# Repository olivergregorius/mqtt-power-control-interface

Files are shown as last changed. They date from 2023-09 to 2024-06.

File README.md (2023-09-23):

# mqtt-power-control-interface



## Introduction

Micropython project for front panel header power control using the MQTT protocol

## Hardware

This project includes a Kicad project providing schematics and a board layout for placing a Raspberry Pi Pico W on it. The microcontroller acts as a lightweight
MQTT client publishing and controlling the power state of up to 12 devices that are connected via the "Intel 9-pin header" (front panel header):

!TODO include picture of front panel header here!

The microcontroller and the devices are not directly connected, instead, they are galvanically isolated from each other by optocouplers, mitigating the risk of
damage.

The power state is determined by the state of the device's power LED pins. It is active low from the microcontroller's perspective.

The power state is controlled by shorting the device's power button pins for 500 milliseconds. That means if the device initially is powered off, it will be
powered on after the power button pins have been shortened. Powering off the machine is up to the operating system's power management, e.g. on Ubuntu if the
power button is pressed shortly (500 milliseconds are sufficient) a shutdown will be initiated, powering off the device.

Thus, each device can be controlled by two GPIO pins of the microcontroller: one for the power state check, one for the power button control.

## Software

This project is written in Micropython and can be flashed onto various microcontroller boards, e.g. the Raspberry Pi Pico W.

### Required Libraries

- umqtt.simple
- micropython_ota (see [https://github.com/olivergregorius/micropython_ota](https://github.com/olivergregorius/micropython_ota))
- micropython_loki (see [https://github.com/olivergregorius/micropython_loki](https://github.com/olivergregorius/micropython_loki))

### Required Files

The following files are required to be flashed onto the microcontroller:

- `boot.py` - Bootup script containing routines for establishing WiFi connection and installing required libraries
- `mqtt.py` - MQTT client library
- `types.py` - Utility file containing type definitions
- `utils.py` - Utility file containing utility methods
- `main.py` - Main routine
- `config.py` - Config file, see `config.template.py` as reference, the keys are self explanatory

### Message Formats

The message format is JSON.

#### Power State

The power state for each device is published to the topic defined in the config in a dedicated message for each device:

```json
{
    "deviceName": "device1",
    "state": "stopped"
}
```

The `state` attribute can take the values `stopped` and `running`.

#### Power Control

The power state for each device can be controlled by sending a dedicated message for each device to the defined topic in the config:

```json
{
    "deviceName": "device1",
    "action": "powerOn"
}
```

The `action` attribute can take the values `powerOn` and `powerOff`, whereas for now both of the actions trigger a 500 millisecond power button push, regardless
of the current state of the device.

## Disclaimer

This hardware/software is provided "as is", and you use the hardware/software at your own risk. Under no circumstances shall any author be liable for direct,
indirect, special, incidental, or consequential damages resulting from the use, misuse, or inability to use this hardware/software, even if the authors have
been advised of the possibility of such damages.

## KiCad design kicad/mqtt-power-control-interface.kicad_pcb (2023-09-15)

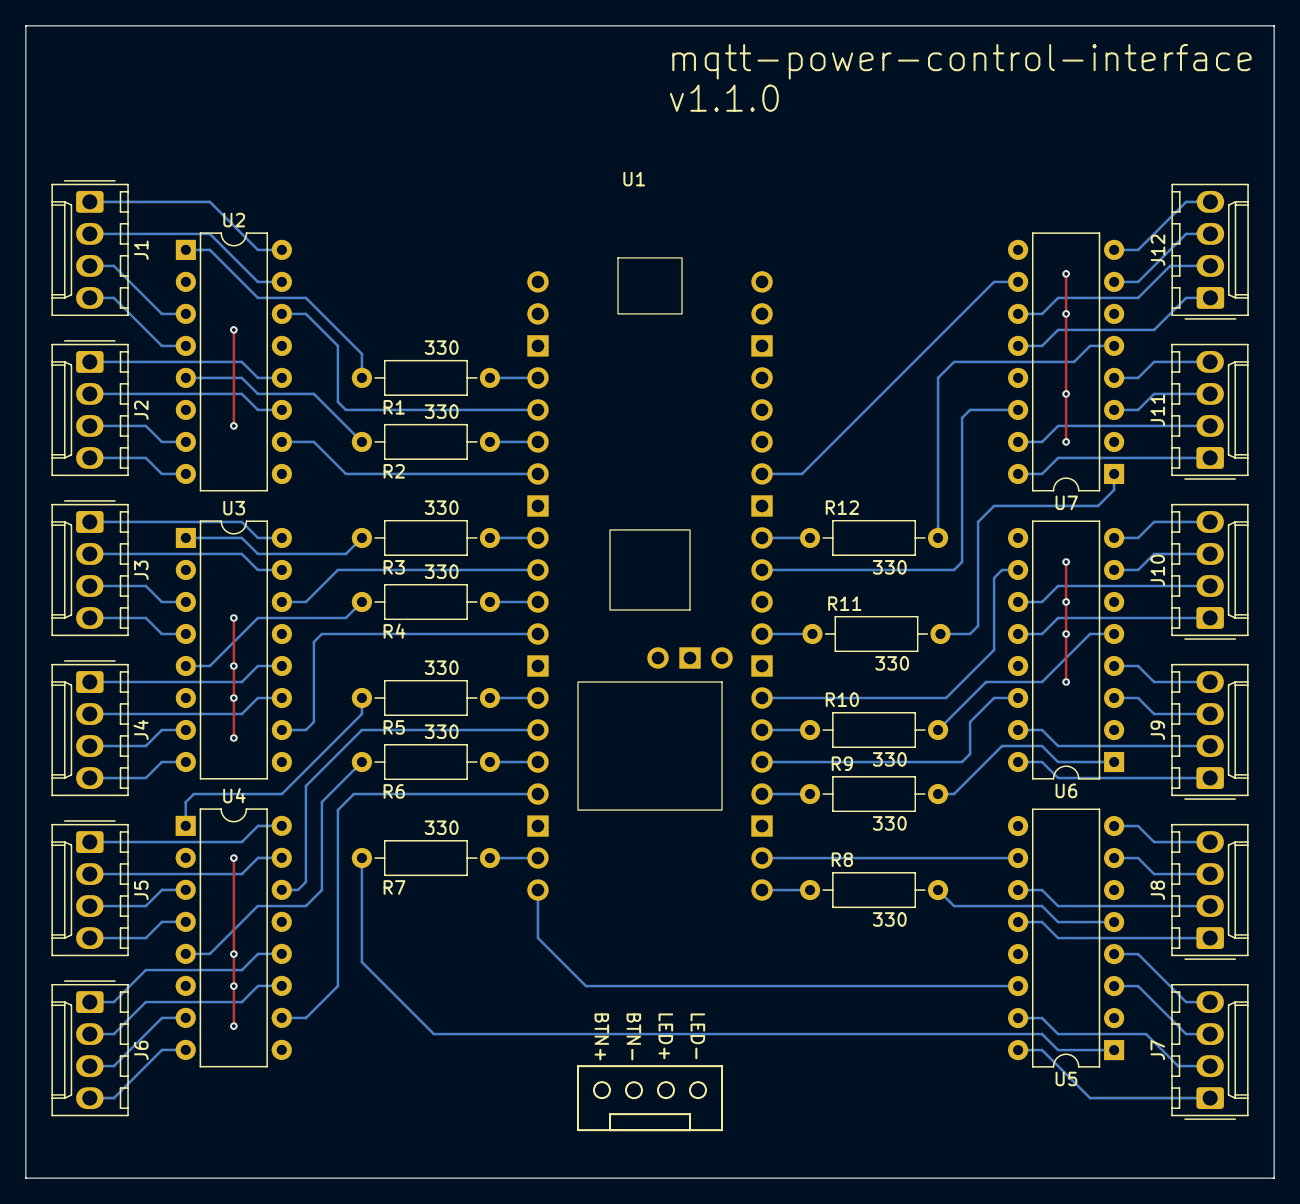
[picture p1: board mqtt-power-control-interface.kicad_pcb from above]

Board: 2 copper layers, 99.1 x 91.4 mm, 31 parts (0 on the bottom side), 85 nets.

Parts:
J1, J2, J3, J4, J5, J6, J7, J8, J9, J10, J11, J12: Conn_01x04_Pin; Molex_KK-254_AE-6410-04A_1x04_P2.54mm_Vertical
R1, R2, R3, R4, R5, R6, R7, R8, R9, R10, R11, R12: 330; R_Axial_DIN0207_L6.3mm_D2.5mm_P10.16mm_Horizontal
U1: RPi Pico W; RPI Pico W
U2, U3, U4, U5, U6, U7: LTV-847; DIP-16_W7.62mm

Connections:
DEV1_LED+: J1.3, U2.3
DEV1_LED-: J1.4, U2.4
DEV1_SW+: J1.1, U2.16
DEV1_SW-: J1.2, U2.15
DEV2_LED+: J2.3, U2.7
DEV2_LED-: J2.4, U2.8
DEV2_SW+: J2.1, U2.12
DEV2_SW-: J2.2, U2.11
DEV3_LED+: J3.3, U3.3
DEV3_LED-: J3.4, U3.4
DEV3_SW+: J3.1, U3.16
DEV3_SW-: J3.2, U3.15
DEV4_LED+: J4.3, U3.7
DEV4_LED-: J4.4, U3.8
DEV4_SW+: J4.1, U3.12
DEV4_SW-: J4.2, U3.11
DEV5_LED+: J5.3, U4.3
DEV5_LED-: J5.4, U4.4
DEV5_SW+: J5.1, U4.16
DEV5_SW-: J5.2, U4.15
DEV6_LED+: J6.3, U4.7
DEV6_LED-: J6.4, U4.8
DEV6_SW+: J6.1, U4.12
DEV6_SW-: J6.2, U4.11
DEV7_LED+: J7.3, U5.3
DEV7_LED-: J7.4, U5.4
DEV7_SW+: J7.1, U5.16
DEV7_SW-: J7.2, U5.15
DEV8_LED+: J8.3, U5.7
DEV8_LED-: J8.4, U5.8
DEV8_SW+: J8.1, U5.12
DEV8_SW-: J8.2, U5.11
DEV9_LED+: J9.3, U6.3
DEV9_LED-: J9.4, U6.4
DEV9_SW+: J9.1, U6.16
DEV9_SW-: J9.2, U6.15
DEV10_LED+: J10.3, U6.7
DEV10_LED-: J10.4, U6.8
DEV10_SW+: J10.1, U6.12
DEV10_SW-: J10.2, U6.11
DEV11_LED+: J11.3, U7.3
DEV11_LED-: J11.4, U7.4
DEV11_SW+: J11.1, U7.16
DEV11_SW-: J11.2, U7.15
DEV12_LED+: J12.3, U7.7
DEV12_LED-: J12.4, U7.8
DEV12_SW+: J12.1, U7.12
DEV12_SW-: J12.2, U7.11
GND: U1.3 (GND1), U1.8 (GND2), U1.13 (GND3), U1.18 (GND4), U1.23 (GND5), U1.28 (GND6), U1.33 (GND7), U1.38 (GND8), U1.42 (GND_DEBUG), U2.2, U2.6, U2.9, U2.13, U3.2, U3.6, U3.9, U3.13, U4.2, U4.6, U4.9, U4.13, U5.2, U5.6, U5.9, U5.13, U6.2, U6.6, U6.9, U6.13, U7.2, U7.6, U7.9, U7.13
GPIO2: R1.1, U1.4 (GP2)
GPIO3: U1.5 (GP3), U2.14
GPIO4: R2.1, U1.6 (GP4)
GPIO5: U1.7 (GP5), U2.10
GPIO6: R3.1, U1.9 (GP6)
GPIO7: U1.10 (GP7), U3.14
GPIO8: R4.1, U1.11 (GP8)
GPIO9: U1.12 (GP9), U3.10
GPIO10: R5.1, U1.14 (GP10)
GPIO11: U1.15 (GP11), U4.14
GPIO12: R6.1, U1.16 (GP12)
GPIO13: U1.17 (GP13), U4.10
GPIO14: R7.1, U1.19 (GP14)
GPIO15: U1.20 (GP15), U5.14
GPIO16: R8.1, U1.21 (GP16)
GPIO17: U1.22 (GP17), U5.10
GPIO18: R9.1, U1.24 (GP18)
GPIO19: U1.25 (GP19), U6.14
GPIO20: R10.1, U1.26 (GP20)
GPIO21: U1.27 (GP21), U6.10
GPIO22: R11.1, U1.29 (GP22)
GPIO26: U1.31 (GP26), U7.14
GPIO27: R12.1, U1.32 (GP27)
GPIO28: U1.34 (GP28), U7.10
unnamed: R1.2, U2.1
unnamed: R2.2, U2.5
unnamed: R3.2, U3.1
unnamed: R4.2, U3.5
unnamed: R5.2, U4.1
unnamed: R6.2, U4.5
unnamed: R7.2, U5.1
unnamed: R8.2, U5.5
unnamed: R9.2, U6.1
unnamed: R10.2, U6.5
unnamed: R11.2, U7.1
unnamed: R12.2, U7.5

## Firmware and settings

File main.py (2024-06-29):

import gc

import machine
import micropython_ota
import ntptime
import ujson
import usys
import utime
from micropython_loki import Loki, LogLevel
from uio import StringIO

from config import led_pin, ntp_config, ota_config, mqtt_config, loki_config, devices
from mqtt import MQTTClient
from types import Device

check_msg_interval_seconds = 1
state_report_interval_seconds = 5

pin_led = machine.Pin(led_pin, machine.Pin.OUT)
ntptime.host = ntp_config.host


# Signals:
# Start: 5, 100, 100
# OTA update: 3, 500, 200
def blink(count: int, on_duration_ms=1000, off_duration_ms=1000) -> None:
    pin_led.off()
    for i in range(count):
        pin_led.on()
        utime.sleep_ms(on_duration_ms)
        pin_led.off()
        utime.sleep_ms(off_duration_ms)


def ntp_update(current_time: int) -> None:
    global last_ntp_update
    attempts = 0
    while attempts < ntp_config.update_attempts:
        attempts += 1
        try:
            ntptime.settime()
        except Exception as e:
            loki.log('Error synchronizing with time server, performing reset...', LogLevel.ERROR)
            stacktrace = StringIO()
            usys.print_exception(e, stacktrace)
            loki.log(f'ntp_update: {stacktrace.getvalue()}', LogLevel.ERROR)
            push_logs(current_time)
            machine.reset()
        if ntp_config.lower_bound < utime.time() < ntp_config.upper_bound:
            last_ntp_update = current_time
            return
    loki.log(f'Error synchronizing with time server, current time {utime.time()}, performing reset...', LogLevel.ERROR)
    push_logs(current_time)
    machine.reset()


def push_logs(current_time: int) -> None:
    global last_loki_push_logs
    last_loki_push_logs = current_time
    loki.push_logs()


def msg_callback(topic, msg):
    global triggered_devices
    msg_json = ujson.loads(msg.decode())
    loki.log(f'Received message: {msg_json}')
    device_name = msg_json['deviceName']
    matching_device = [device for device in devices if device.name == device_name]
    if not matching_device:
        loki.log(f'No matching device with name {device_name} could be found')
        return
    triggered_devices.extend(matching_device)


def push_pwr_button(device: Device) -> None:
    loki.log(f'Pushing power button for device {device.name}')
    device.pwr_btn_pin.value(1)
    utime.sleep_ms(500)
    device.pwr_btn_pin.value(0)


# main
blink(5, 100, 100)
current_time = utime.time()
last_state_report = current_time
last_loki_push_logs = 0
last_ota_update = current_time
last_ntp_update = current_time
loki = Loki(loki_config.url, loki_config.labels, max_stack_size=loki_config.max_stack_size, min_push_log_level=loki_config.min_push_log_level)
loki.log('Starting mqtt-power-control-interface')
mqtt = MQTTClient(client_id=mqtt_config.client_id, server=mqtt_config.host, port=mqtt_config.port, user=mqtt_config.username, password=mqtt_config.password)
mqtt.set_callback(msg_callback)
mqtt.safe_connect_and_subscribe()
triggered_devices = []
while True:
    try:
        current_time = utime.time()

        mqtt.check_msg()
        while triggered_devices:
            push_pwr_button(triggered_devices.pop())

        if current_time % state_report_interval_seconds == 0 or current_time >= last_state_report + state_report_interval_seconds:
            for device in devices:
                pwr_state = 'running' if device.pwr_led_pin.value() == 0 else 'stopped'
                loki.log(f'Determined power state for device {device.name}: {pwr_state}', LogLevel.DEBUG)
                mqtt.publish(topic=mqtt_config.topic_pwr_state, msg=f'{{"deviceName": "{device.name}", "state": "{pwr_state}"}}')
            last_state_report = current_time

        if current_time > last_ota_update + ota_config.interval_s:
            blink(3, 500, 200)
            loki.log('Checking for OTA update')
            last_ota_update = current_time
            micropython_ota.check_for_ota_update(ota_config.url, ota_config.project, soft_reset_device=True)
            gc.collect()

        if current_time > last_ntp_update + ntp_config.update_interval_s:
            ntp_update(current_time)

        if current_time > last_loki_push_logs + loki_config.push_interval_s:
            push_logs(current_time)

        utime.sleep(1)
    except KeyboardInterrupt:
        exit(1)
    except Exception as e:
        stacktrace = StringIO()
        usys.print_exception(e, stacktrace)
        loki.log(f'main.py: {stacktrace.getvalue()}', LogLevel.ERROR)
        push_logs(current_time)

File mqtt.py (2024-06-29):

from umqtt import simple
import utime

from config import mqtt_config


class MQTTClient(simple.MQTTClient):

    def safe_connect_and_subscribe(self):
        while True:
            try:
                super().disconnect()
            except:
                pass
            try:
                result = super().connect()
                self.subscribe(topic=mqtt_config.topic_pwr_control)
                return result
            except OSError:
                utime.sleep(2)

    def publish(self, topic, msg: str):
        while True:
            try:
                return super().publish(topic, msg.encode())
            except OSError:
                pass
            self.safe_connect_and_subscribe()

    def subscribe(self, topic):
        super().subscribe(topic)

    def set_callback(self, function):
        super().set_callback(function)

    def check_msg(self):
        try:
            super().check_msg()
        except OSError:
            self.safe_connect_and_subscribe()

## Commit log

2023-08-02 Code optimizations, added first schematic and board draft
    [mqtt-power-control-interface.kicad_pcb, mqtt-power-control-interface.kicad_sch]
2023-08-02 Removed duplicate kicad project folder
2023-08-07 Fixed instability issue in mqtt client
    [mqtt.py]
2023-08-07 Enhanced schematic and board
    [interface.kicad_sch, mqtt-power-control-interface.kicad_pcb, mqtt-power-control-interface.kicad_sch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]
2023-08-07 Removed kicad backups folder
2023-09-15 Code optimization, included micropython_loki and micropython_ota libraries, improved failsafeness
    [boot.py, config.template.py, main.py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]
2023-09-15 Updated board, using THT resistors, fixed wiring
    [interface.kicad_sch, mqtt-power-control-interface.kicad_pcb, mqtt-power-control-interface.kicad_sch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]
2024-06-29 v1.0.2: Fixed reconnect behavior on issues
    [main.py, mqtt.py]
